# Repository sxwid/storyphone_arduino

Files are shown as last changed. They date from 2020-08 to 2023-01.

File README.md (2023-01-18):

# storyphone Arduino Shield
Wählscheibentelefon MP3 Player

Code und Hardware für ein Arduino Shield. Funktionen und Details:
- Speisung 24VDC (Ein 6W Netzteil reicht)
- Schaltregler um 5V für das MP3 Modul und 9V für den Arduino VIN zu generieren (getrennt wegen Störungen des MP3 Moduls)
- Ausgabe Leitungston über DIO2
- Detektion der Gabelzustände und Wählimpulse über Optokoppler und DIO4
- USB Stick (FAT32) mit Dateien im Rootfolder:
  - 0001.mp3 für Zahl 1
  - 0002.mp3 für Zahl 2 
  -  etc 
  - 0009.mp3 für Zahl 9
  - 0010.mp3 für Zahl 0
- Volume der Audiowiedergabe kann am Drehknopf eingestellt werden

!!! Funktioniert bei mir nur mit einem Original Arduino (mit Klon bei Speisung über VIN erst nach manuellem Drücken des Reset Buttons).

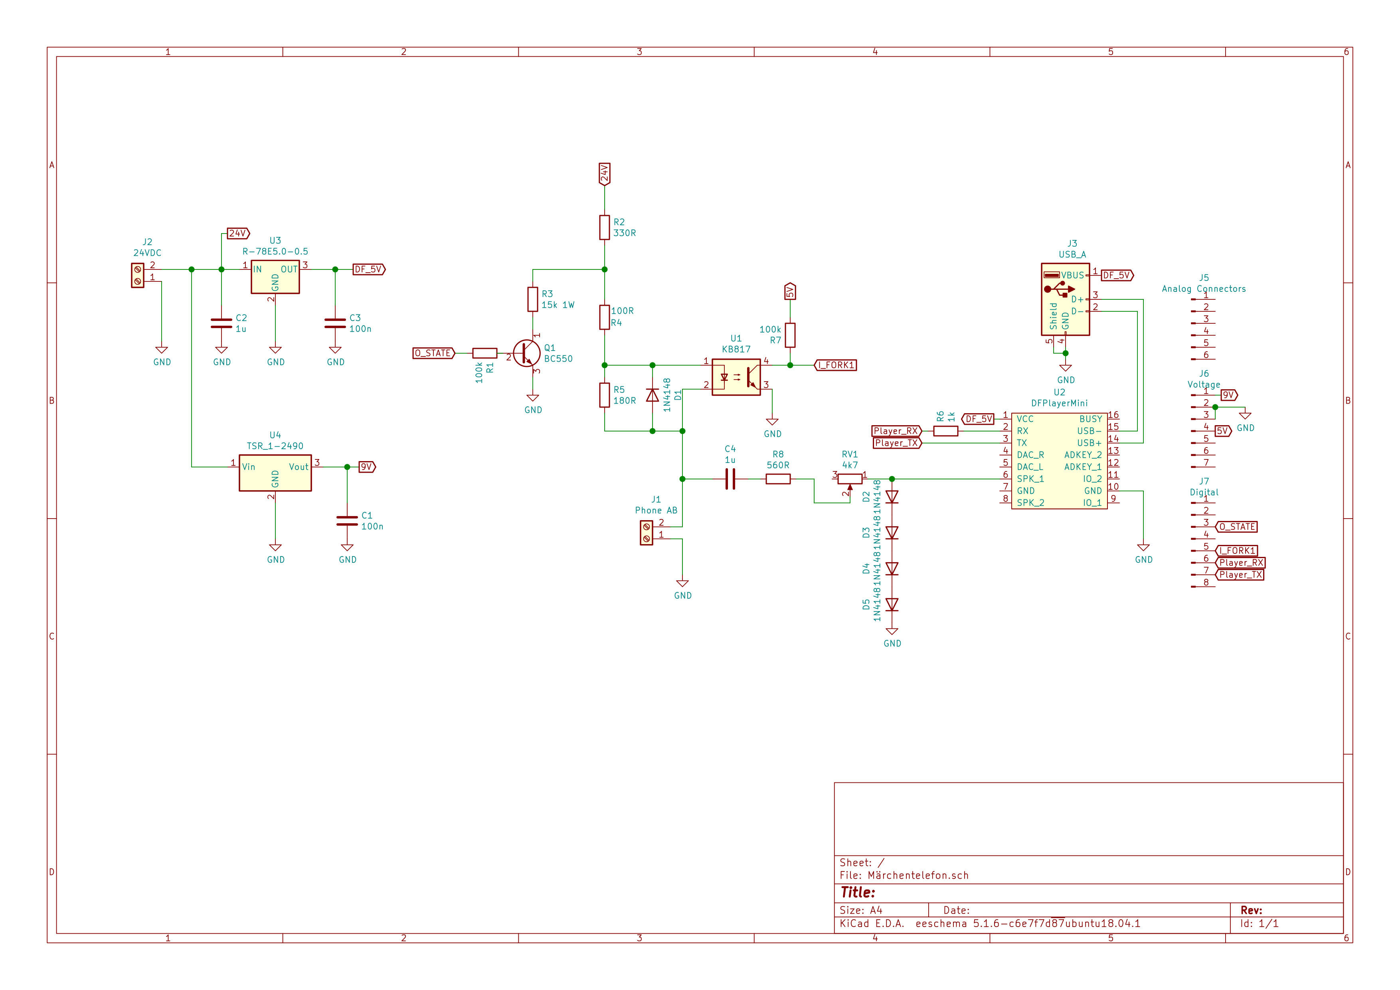
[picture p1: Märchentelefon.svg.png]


Hier noch das Schema für die Autophon Geräte



Bei Standardkabelbelegung gilt:
- a Draht weiss (a)
- b Draht blau (b) 
- c Draht türkis (Wecker)
- d Draht violett

Da wir den Wecker nicht benötigen können der weisse und der blaue Draht verwendet werden.

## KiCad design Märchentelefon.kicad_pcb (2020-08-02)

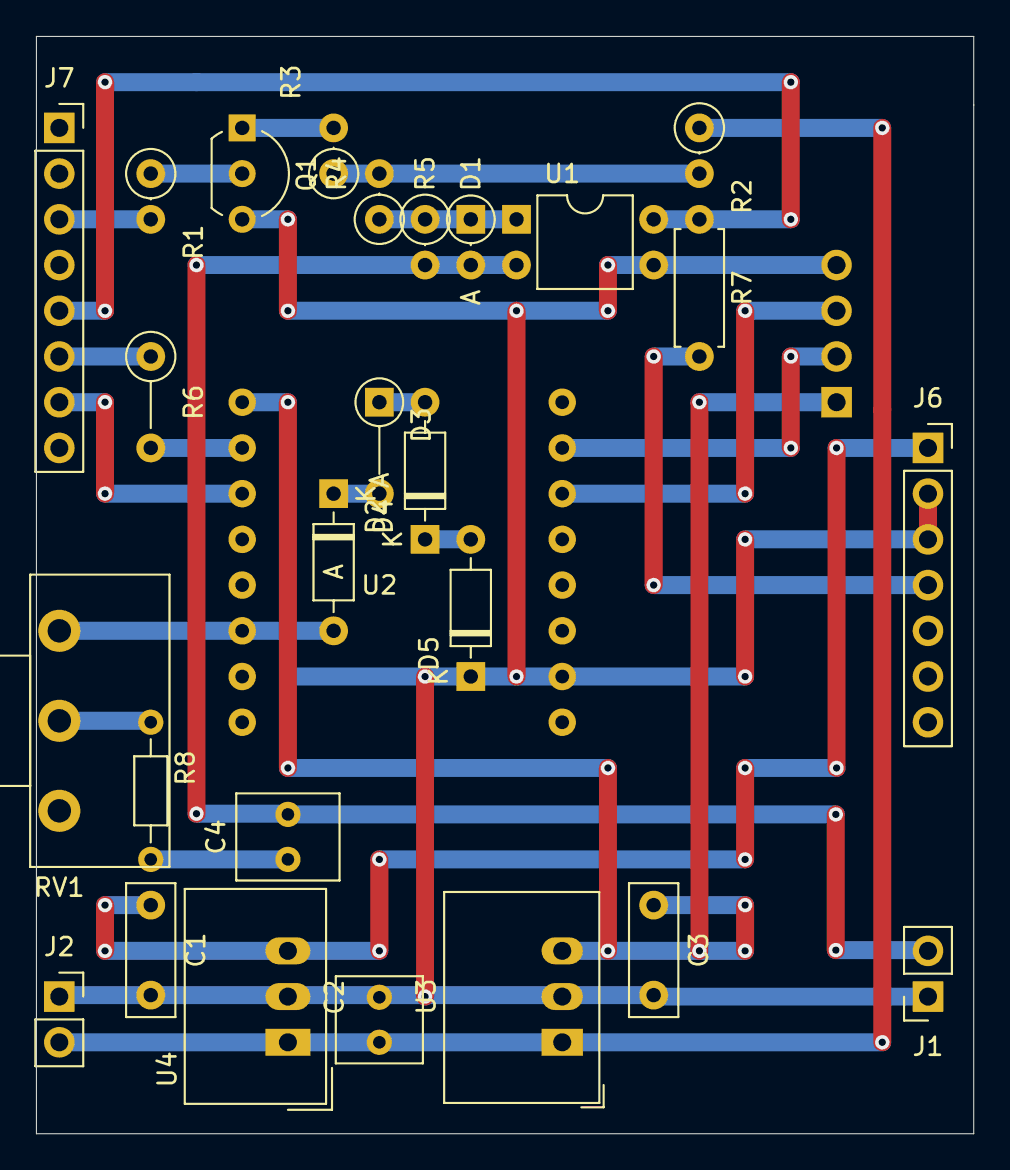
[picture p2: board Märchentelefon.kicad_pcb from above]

Board: 2 copper layers, 52.1 x 61.0 mm, 28 parts (1 on the bottom side), 23 nets.

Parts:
C1, C3: 100n; C_Rect_L7.2mm_W2.5mm_P5.00mm_FKS2_FKP2_MKS2_MKP2
C2: 1u; C_Rect_L4.6mm_W4.6mm_P2.50mm_MKS02_FKP02
C4: 1u; C_Rect_L4.6mm_W5.5mm_P2.50mm_MKS02_FKP02
D1: 1N4148; D_DO-35_SOD27_P2.54mm_Vertical_AnodeUp
D2, D4, D5: 1N4148; D_DO-35_SOD27_P7.62mm_Horizontal
D3: 1N4148; D_DO-35_SOD27_P5.08mm_Vertical_AnodeUp
J1: Phone AB; PinSocket_1x02_P2.54mm_Vertical
J2: 24VDC; PinSocket_1x02_P2.54mm_Vertical
J3: USB_A; PinHeader_1x04_P2.54mm_Horizontal
J6: Voltage; PinSocket_1x07_P2.54mm_Vertical
J7: Digital; PinSocket_1x08_P2.54mm_Vertical
Q1: BC550; TO-92L_Inline_Wide
R1: 100k; R_Axial_DIN0207_L6.3mm_D2.5mm_P2.54mm_Vertical
R2: 330R; R_Axial_DIN0207_L6.3mm_D2.5mm_P2.54mm_Vertical
R3: 15k 1W; R_Axial_DIN0207_L6.3mm_D2.5mm_P2.54mm_Vertical
R4: 100R; R_Axial_DIN0207_L6.3mm_D2.5mm_P2.54mm_Vertical
R5: 180R; R_Axial_DIN0207_L6.3mm_D2.5mm_P2.54mm_Vertical
R6: 1k; R_Axial_DIN0207_L6.3mm_D2.5mm_P5.08mm_Vertical
R7: 100k; R_Axial_DIN0207_L6.3mm_D2.5mm_P7.62mm_Horizontal
R8: 560R; R_Axial_DIN0204_L3.6mm_D1.6mm_P7.62mm_Horizontal
RV1: 4k7; Potentiometer_Piher_T-16H_Single_Horizontal
U1: KB817; DIP-4_W7.62mm
U2: DFPlayerMini; DFPlayer_V2
U3: R-78E5.0-0.5; Converter_DCDC_RECOM_R-78E-0.5_THT
U4: TSR_1-2490; Converter_DCDC_TRACO_TSR-1_THT

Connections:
5V: J6.4, R7.2
9V: C1.1, J6.1, U4.3
24V: C2.1, J2.2, R2.1, U3.1, U4.1
DF_5V: C3.1, J3.1, U2.1, U3.3
GND: C1.2, C2.2, C3.2, D5.1, J1.1, J2.1, J3.4, J6.2, J6.3, Q1.3, U1.3, U2.10, U3.2, U4.2
I_FORK1: J7.5, R7.1, U1.4
unnamed: C4.1, R8.2
unnamed: C4.2, D1.2, J1.2, R5.2, U1.2
unnamed: D1.1, R4.1, R5.1, U1.1
unnamed: D2.1, D3.2
unnamed: D2.2, RV1.1, U2.6
unnamed: D3.1, D4.2
unnamed: D4.1, D5.2
unnamed: J3.2, U2.15
unnamed: J3.3, U2.14
unnamed: Q1.1, R3.2
unnamed: Q1.2, R1.1
unnamed: R2.2, R3.1, R4.2
unnamed: R6.2, U2.2
unnamed: R8.1, RV1.2
O_STATE: J7.3, R1.2
Player_RX: J7.6, R6.1
Player_TX: J7.7, U2.3

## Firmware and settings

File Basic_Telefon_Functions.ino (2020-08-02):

#include <PlayRtttl.h>
#include "SoftwareSerial.h"
#include "DFRobotDFPlayerMini.h"

float vers = 1.0;

SoftwareSerial mySoftwareSerial(6, 5); // RX, TX
DFRobotDFPlayerMini myDFPlayer;

const int Itel1 = 4;    // Telefon 1 Auswertung Gabel und Wählpulse
const int OAudio = 2; // Signalausgabe auf die unbeschaltenen Telefone (nicht, wenn auf internen AB Leitungen)

bool forkup = false; //ist die Gabel abgehoben
bool last_forkstate = HIGH; // letzter Zustand der Gabel
bool action_completed = true; // Prüfen, ob eine fertigstellung der Auswertung offen ist (Wählen / Gabel)
int dial_counter = 0;

// Timings
int pulse = 60; //ms
int pulse_min = pulse*0.9; //ms
int pulse_max = pulse*1.1; //ms
int pause = 40; //ms
int pause_min = pause*0.9; //ms
int pause_max = pause*1.1; //ms
int period_max = 10* (pulse_max + pause_max);

//DF Player Settings
int df_vol = 30;

unsigned long lastchange = 0; //last time fork changed


void setup() {
  mySoftwareSerial.begin(9600);
  Serial.begin(115200);
  Serial.println();
  Serial.print("Telefonzentrale ");
  Serial.println (vers);
  Serial.print("_|‾|_ Pulsmin: ");
  Serial.print (pulse_min);
  Serial.print(" Pulsmax: ");
  Serial.print (pulse_max);
  Serial.print("       ‾|_|‾ Pausemin: ");
  Serial.print (pause_min);
  Serial.print(" Pausemax: ");
  Serial.print (pause_max);
  Serial.print(" Periodemax: ");
  Serial.println (period_max);

  if (!myDFPlayer.begin(mySoftwareSerial)) {  //Use softwareSerial to communicate with mp3.
    Serial.println(F("Unable to begin:"));
    Serial.println(F("1.Please recheck the connection!"));
    Serial.println(F("2.Please insert the SD card!"));
    while(true){
      delay(0); // Code to compatible with ESP8266 watch dog.
    }
  }
  Serial.println(F("DFPlayer Mini online."));

  myDFPlayer.outputDevice(DFPLAYER_DEVICE_U_DISK);
  myDFPlayer.volume(df_vol);
  myDFPlayer.EQ(DFPLAYER_EQ_NORMAL);
  
  pinMode(Itel1, INPUT);

}

void led_blink(){
  digitalWrite(LED_BUILTIN, HIGH);   // turn the LED on (HIGH is the voltage level)
  delay(500);                       // wait for a second
  digitalWrite(LED_BUILTIN, LOW);    // turn the LED off by making the voltage LOW
  delay(500);                       // wait for a second
}

void forkstatechange(bool state){
  // Alle vorgängigen Aktionen sind abgeschlossen. Also wird die Gabel neu abgehoben.
  if (forkup == false && state == LOW && action_completed == true){
    forkup = true;
    last_forkstate = LOW;
    Serial.println("Hörer abgehoben");
    signal_line();
  }

  // Der Hörer war abgenommen, also wurde entweder aufgelegt oder es wird gewählt
  if (forkup == true){
    
    // Alle vorgängigen Aktionen waren beendet, entweder ist es der erste Wählimpuls oder es wurde aufgelegt
    if (state == HIGH && action_completed == true){
      // DF Player pausieren - entweder will jemand einen neuen Track oder hat aufgehängt.
      myDFPlayer.pause();
      // Falls ein Signalton ausgegeben wurde, beenden
      noTone(OAudio);
      lastchange = millis();
      last_forkstate = HIGH;
      action_completed = false;
      //Serial.print("Gabel aufgelegt oder Wählvorgang, weiter beobachten ...");
    }
    //Aktion ist nicht beendet und es folgt ein neuer Impuls, also ist ein Wählvorgang im Gange
    else if (state == LOW && action_completed == false){
      lastchange = millis();
      last_forkstate = LOW;
      action_completed = false;
      // Zähler wird auf fallender Flanke erhöht um das auflegen detektieren zu können
      dial_counter += 1; // Addiere eins zum Zähler
      //Serial.print(" ");
      //Serial.print(dial_counter);
    }   
    //Aktion ist nicht beendet und es folgt ein neuer Impuls, also ist ein Wählvorgang im Gange
    else if (state == HIGH && action_completed == false){
      lastchange = millis();
      last_forkstate = HIGH;
      action_completed = false;
    } 
  }
}

void check_action(){
  // Hier lande ich nur, wenn innert 1 Pulslänge nichts mehr passiert ist.
  // Entweder wurde also die Gabel aufgehängt wurde oder beim letzten Wählimpuls 

  //Steht der Counter noch bei 0 so wurde die Gabel aufgehängt
  if (dial_counter == 0){
    stopPlayRtttl();
    forkup = false;
    last_forkstate = HIGH;
    Serial.println("Hörer aufgelegt");
  }
  else{
    // mfPlayer braucht Zahlen von 1 bis 10 also wird 0 die zehn.
    myDFPlayer.play(dial_counter);
    if(dial_counter==10){dial_counter=0;}

    Serial.print("Nummer: ");
    Serial.println(dial_counter);
    dial_counter = 0;
  }
  action_completed = true;    
  lastchange = 0;
}

void play_sound(int track){
  switch(track){
    case 0: myDFPlayer.play(10);break;
    case 1: myDFPlayer.play(1);break;
    case 2: myDFPlayer.play(2);break;
    case 3: myDFPlayer.play(3);break;
    case 4: myDFPlayer.play(4);break;
    case 5: myDFPlayer.play(5);break;
    case 6: myDFPlayer.play(6);break;
    case 7: myDFPlayer.play(7);break;
    case 8: myDFPlayer.play(8);break;
    case 9: myDFPlayer.play(9);break;
//    case 1: playRtttlBlockingPGM(OAudio, Bond);break;
//    case 2: playRtttlBlockingPGM(OAudio, YMCA);break;
//    case 3: playRtttlBlockingPGM(OAudio, Smurfs);break;
//    case 4: playRtttlBlockingPGM(OAudio, Short);break;
//    case 5: playRtttlBlockingPGM(OAudio, YMCA);break;
//    case 6: playRtttlBlockingPGM(OAudio, YMCA);break;
//    case 7: playRtttlBlockingPGM(OAudio, YMCA);break;
//    case 8: playRtttlBlockingPGM(OAudio, YMCA);break;
//    case 9: playRtttlBlockingPGM(OAudio, YMCA);break;
//    case 0: playRtttlBlockingPGM(OAudio, YMCA);break;
  }
}

void signal_nocard(){
  tone(OAudio, 880, 1000);
}

void signal_nofile(){
  tone(OAudio, 880, 3000);
}

void signal_line(){
  tone(OAudio,440);
}

void printDetail(uint8_t type, int value){
  switch (type) {
    case TimeOut:
      Serial.println(F("Time Out!"));
      break;
    case WrongStack:
      Serial.println(F("Stack Wrong!"));
      break;
    case DFPlayerCardInserted:
      Serial.println(F("Card Inserted!"));
      break;
    case DFPlayerCardRemoved:
      Serial.println(F("Card Removed!"));
      break;
    case DFPlayerCardOnline:
      Serial.println(F("Card Online!"));
      break;
    case DFPlayerUSBInserted:
      Serial.println("USB Inserted!");
      break;
    case DFPlayerUSBRemoved:
      Serial.println("USB Removed!");
      break;
    case DFPlayerPlayFinished:
      Serial.print(F("Number:"));
      Serial.print(value);
      Serial.println(F(" Play Finished!"));
      break;
    case DFPlayerError:
      Serial.print(F("DFPlayerError:"));
      switch (value) {
        case Busy:
          signal_nocard();
          Serial.println(F("Card not found"));
          break;
        case Sleeping:
          Serial.println(F("Sleeping"));
          break;
        case SerialWrongStack:
          Serial.println(F("Get Wrong Stack"));
          break;
        case CheckSumNotMatch:
          Serial.println(F("Check Sum Not Match"));
          break;
        case FileIndexOut:
          Serial.println(F("File Index Out of Bound"));
          break;
        case FileMismatch:
          signal_nofile();
          Serial.println(F("Cannot Find File"));
          break;
        case Advertise:
          Serial.println(F("In Advertise"));
          break;
        default:
          break;
      }
      break;
    default:
      break;
  }
  
}
void loop() {
  bool forkstate = digitalRead(Itel1);

  //Serial.print(forkstate);
  if (forkstate != last_forkstate){
    forkstatechange(forkstate);
  }
  if (action_completed == false && millis() > (lastchange + pulse_max)){
    check_action();
  }
    
  if (myDFPlayer.available()) {
    printDetail(myDFPlayer.readType(), myDFPlayer.read()); //Print the detail message from DFPlayer to handle different errors and states.
  }
  delay(1);
  }
